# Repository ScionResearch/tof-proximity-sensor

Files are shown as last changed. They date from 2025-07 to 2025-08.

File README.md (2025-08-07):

# ESP32-C6 Configurable Proximity Sensor

**Version 1.0.1** - A configurable proximity sensor system built with ESP32-C6, featuring real-time web-based monitoring, advanced adaptive filtering, and secure OTA firmware updates.



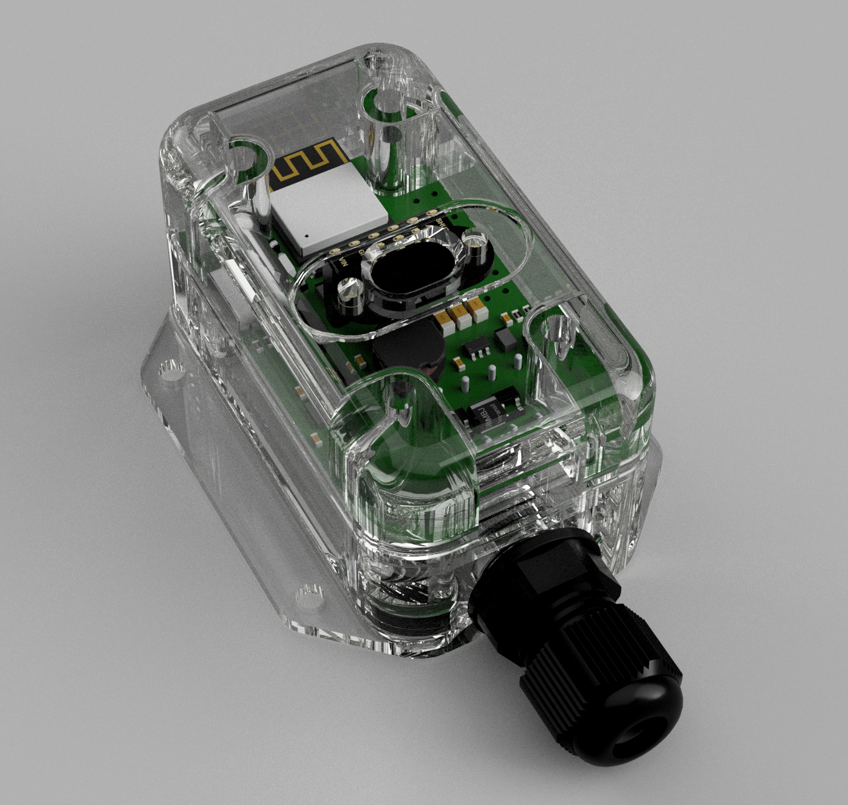
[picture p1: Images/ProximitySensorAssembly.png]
Proximity Sensor Assembly


## Features

### **🎯 Core Functionality**

- **VL53L1X ToF Sensor** - Accurate distance measurement up to 4 meters
- **Advanced Adaptive Filtering** - Intelligent noise reduction with rapid adaptation to sustained changes
- **Variance-Based Noise Detection** - Automatic detection and filtering of noisy environments
- **Dual Configurable Outputs** - Independent range, hysteresis, and polarity control
- **Smart Fault Detection** - Distinguishes genuine sensor faults from normal out-of-range conditions
- **Automatic Recovery** - Self-healing sensor initialization with enhanced reliability
- **Rapid Response Fix** - Outputs properly reset when objects are quickly removed

### **🌐 Web Interface**

- **Real-time Monitoring** - 5Hz update rate for smooth feedback
- **Live Configuration** - Adjust ranges, hysteresis, and polarity without reprogramming
- **Individual Output Control** - Enable/disable each output independently
- **Password Authentication** - Secure access with configurable admin password
- **Dynamic Visual Feedback** - Color-coded status and output indicators
- **Mobile-Optimized Design** - Clean, touch-friendly interface for smartphones
- **iOS Compatibility** - Enhanced captive portal support for reliable iPhone/iPad access

### **🔄 Over-The-Air (OTA) Updates**

- **Secure Firmware Updates** - Upload new firmware directly through web interface
- **Multi-Layer Security** - File validation, size checks, and integrity verification
- **Visual Feedback** - Orange LED indication during firmware update process
- **Progress Monitoring** - Real-time upload progress with detailed status messages
- **Safe Recovery** - Automatic rollback on failed updates with device protection

### **🔧 Hardware Integration**

- **WS2812 RGB LED** - Enhanced visual status indication:
  - **Green**: Normal operation (pulsing effect)
  - **Blue**: Triggered state
  - **Red**: Sensor fault or error
  - **Orange**: Firmware update in progress
- **Two Digital Outputs** - Configurable trigger logic with hysteresis
- **Persistent Storage** - Configuration saved to LittleFS flash memory
- **Unique WiFi SSID** - MAC-based identifier for multi-sensor deployments (fixed in v1.0.0)
- **Enhanced Diagnostics** - Comprehensive serial logging for troubleshooting

## Hardware Requirements

### **Main Components**

- **ESP32-C6-Mini** development module
- **VL53L1X** Time-of-Flight distance sensor
- **WS2812** RGB LED (NeoPixel)
- **Custom PCB** with two digital output channels

## Quick Start Guide

### **1. First Boot**

1. Power on the device
2. Look for WiFi network: `ToF-Prox-XXXXXX` (where XXXXXX = last 3 bytes of MAC address)
3. Connect using password: `sensor123`

### **2. Web Interface Access**

1. Open browser and navigate to: `http://192.168.4.1`
2. Login with default credentials:
   - **Password:** `admin`

### **3. Initial Configuration**

1. **Change Admin Password** (recommended):

   - Scroll to "Change Password" section
   - Enter current password: `admin`
   - Set new password and confirm
   - Click "Change Password"
2. **Configure Outputs**:

   - Adjust ranges, hysteresis, and polarity as needed
   - Click "Save Configuration"

## Default Settings

### **Network Configuration**

- **WiFi SSID:** `ToF-Prox-XXXXXX` (unique per device)
- **WiFi Password:** `sensor123`
- **IP Address:** `192.168.4.1`
- **Web Interface:** `http://192.168.4.1`

### **Authentication**

- **Default Admin Password:** `admin`
- **Important:** Change the default password after first login!

## Changelog

### **Version 1.0.1** (Latest)

#### 🔧 **Bug Fixes**
- **Fixed Output Trigger Logic**: Outputs configured as "Active out of range" now properly trigger when sensor readings exceed maximum detection range
- **Improved Out-of-Range Handling**: Enhanced logic for handling sensor readings beyond physical detection limits

#### 📱 **Mobile Enhancements**
- **Smart Firmware Update Restriction**: Firmware update panel automatically hidden on smartphones to ensure updates are only performed from PCs
- **Mobile Device Detection**: JavaScript-based user agent detection prevents accidental firmware updates from mobile devices
- **Enhanced Mobile Layout**: Improved responsive design for better mobile user experience

#### 🎨 **UI/UX Improvements**
- **Professional Layout**: Implemented CSS Grid layout for perfect form field alignment across all sections
- **Consistent Status Cards**: Fixed status card height inconsistencies for better visual alignment
- **Responsive Design**: Enhanced mobile breakpoint handling with single-column layout on small screens
- **Visual Consistency**: Improved spacing, padding, and visual hierarchy throughout the interface

#### 🏢 **Branding**
- **Company Logo Integration**: Embedded BSI logo in header with professional dark background styling
- **Responsive Logo Sizing**: Logo scales appropriately across desktop and mobile devices
- **Enhanced Visual Identity**: Improved page aesthetics with proper logo placement and contrast

#### 🔧 **Technical Improvements**
- **Base64 Logo Embedding**: Optimized logo delivery with embedded encoding for faster loading
- **Improved CSS Architecture**: Better organized stylesheets with consistent naming conventions
- **Enhanced JavaScript**: More robust mobile detection and UI interaction handling

### **Version 1.0.0**
- Initial release with core proximity sensor functionality
- Web-based configuration interface
- OTA firmware update capability
- Advanced adaptive filtering
- Dual configurable outputs

### **Sensor Configuration**

- **Timing Budget:** 50ms
- **Adaptive Filtering:** Intelligent noise reduction with rapid adaptation
- **Variance Threshold:** Automatic noise detection and filtering
- **Update Rate:** 5Hz web interface refresh
- **Change Detection:** Sustained change detection for rapid adaptation

### **Output Defaults**

| Output | Enabled | Min Range | Max Range | Hysteresis | Polarity |
|---|---|---|---|---|---|
| Output 1 | Disabled | 0mm | 100mm | 25mm | Active In Range |
| Output 2 | Disabled | 0mm | 100mm | 25mm | Active In Range |

### **Factory Reset**

- Connect a jumper from GND to the Factory Reset pin (pin 17).
- Power cycle or reset the device, leave the jumper in place until the LED turns green.
- All settings will be reset to default, including web admin password.

## Web Interface Guide

### **Status Monitoring**

- **Distance Display:** Shows actual distance in mm or "Out of range"
- **Status Panel:** Color-coded system status
  - 🟢 Green: Normal operation
  - 🔵 Blue: Output triggered
  - 🔴 Red: Sensor fault
- **Output Status:** Real-time ON/OFF indication with color feedback

### **Configuration Options**

#### **Output Settings**

- **Enable/Disable:** Individual control for each output
  - Unchecked = Output disabled (always OFF)
  - Checked = Output follows detection logic
- **Min/Max Distance:** Set detection range (0-2000mm)
- **Hysteresis:** Prevent output chatter (0-500mm)
- **Polarity:** 
  - "Active In Range" = Output ON when object is between Min-Max
  - "Active Out of Range" = Output ON when object is outside Min-Max

#### **Security Settings**

- **Change Password:** Update admin password with confirmation
- **Logout:** Secure session termination

## LED Status Indicators

| Color | Status | Description |
| --- | --- | --- |
| 🟢**Green** | Normal | Sensor operating normally |
| 🔵**Blue** | Triggered | Object detected in configured range |
| 🔴**Red Blinking** | Fault | Sensor hardware fault detected |
| 🟡**Yellow** | Initializing | System startup in progress |

## Technical Specifications

### **Sensor Performance**

- **Range:** 0mm to 2000mm (typical)
- **Accuracy:** ±3% of distance
- **Update Rate:** Up to 20Hz (50ms timing budget)
- **Field of View:** 27° (full width)

### **System Specifications**

- **Supply Voltage:** +12V-24V DC 100mA max
- **Microcontroller:** ESP32-C6 (160MHz, 320KB RAM, 4MB Flash)
- **WiFi:** 802.11 b/g/n (2.4GHz)
- **Operating Temperature:** -10°C to +60°C

### **Output Specifications**

- **Digital Outputs:** 2 channels open drain
- **Max Voltage at Outputs:** +33V DC
- **Current Capacity:** 100mA per output source capacity
- **Response Time:** <100ms (including hysteresis)

## Development Environment

### **PlatformIO Configuration**

```ini
[env:esp32-c6-devkitm-1]
platform = https://github.com/pioarduino/platform-espressif32/releases/download/54.03.20/platform-espressif32.zip
board = esp32-c6-devkitm-1
framework = arduino
build_flags = 
    -D ARDUINO_USB_MODE=1
    -D ARDUINO_USB_CDC_ON_BOOT=1
    -D ESP32_C6_env
lib_deps = 
    adafruit/Adafruit NeoPixel@^1.15.1
    adafruit/Adafruit VL53L1X@^3.1.2
    bblanchon/ArduinoJson@^7.0.4
    ESP32Async/AsyncTCP
    ESP32Async/ESPAsyncWebServer
```

### **Required Libraries**

- **Adafruit NeoPixel** - WS2812 LED control
- **Adafruit VL53L1X** - ToF sensor interface
- **ArduinoJson** - Configuration serialization
- **ESP32Async/AsyncTCP** - Async networking (ESP32-C6 compatible)
- **ESP32Async/ESPAsyncWebServer** - Web server framework

## Troubleshooting

### **Common Issues**

#### **Cannot Connect to WiFi**

- Verify SSID format: `ToF-Prox-XXXXXX`
- Check password: `sensor123`
- Ensure device is powered and LED is active
- Try power cycling the device

#### **Web Interface Not Loading**

- Confirm connection to correct WiFi network
- Navigate to: `http://192.168.4.1` (not https)
- Clear browser cache if needed
- Try different browser

#### **Sensor Shows "Out of range"**

- Normal when no object is within detection range (0mm-2000mm)
- Check sensor alignment and cleanliness
- Verify object is within sensor field of view (27°)

#### **Outputs Not Triggering**
- **Check if outputs are enabled** - Both outputs are disabled by default for safety
- Verify configuration ranges are appropriate for your application
- Check hysteresis settings (too high may prevent triggering)
- Confirm polarity setting matches your requirements
- Test with known object at specific distance

#### **Red LED (Fault Condition)**

- Power cycle the device (automatic recovery attempts every 5 seconds)
- Check I2C connections to VL53L1X sensor
- Verify sensor is not obstructed or damaged

## Multi-Sensor Deployment

### **Network Planning**

- Each sensor creates unique SSID based on MAC address
- No network conflicts when multiple sensors are deployed
- Individual configuration and monitoring per sensor
- Suitable for industrial and commercial installations

### **Identification**

- SSID format: `ToF-Prox-XXXXXX`
- Serial monitor shows actual SSID during startup
- MAC address visible in device information

## Applications

### **Industrial Automation**

- Conveyor belt object detection
- Material level sensing
- Robotic positioning feedback
- Quality control measurements

### **Security Systems**

- Perimeter detection
- Access control triggers
- Intrusion detection
- Vehicle presence sensing

### **Smart Building**

- Occupancy detection
- Automatic door control
- Parking space monitoring
- Energy management triggers

## Changelog

### **Version 1.0.0** - *August 2025*

#### 🚀 **Major Features**

- **Over-The-Air (OTA) Firmware Updates**
  - Secure web-based firmware upload interface
  - Multi-layer security validation (file type, size, integrity)
  - Visual feedback with orange LED during updates
  - Real-time progress monitoring
  - Automatic rollback on failed updates

- **Advanced Adaptive Filtering System**
  - Replaced simple moving average with intelligent adaptive filter
  - Variance-based noise detection and filtering
  - Rapid adaptation to sustained changes while filtering noise
  - Configurable thresholds for different environments
  - Enhanced signal quality assessment

#### 🔧 **Improvements**

- **Fixed SSID Uniqueness Issue**
  - Resolved static MAC address problem in WiFi AP mode
  - Each device now generates truly unique SSID based on hardware MAC
  - Proper WiFi initialization sequence ensures correct MAC retrieval

- **Enhanced Output Trigger Logic**
  - Fixed output lock-up when objects are quickly removed
  - Outputs now properly reset when sensor goes out of range
  - Improved hysteresis handling for rapid distance changes
  - Added comprehensive debug logging for troubleshooting

- **LED Status Enhancements**
  - Added orange LED indication during firmware updates
  - Enhanced pulsing effects for normal operation
  - Improved visual feedback for all system states

#### 🛡️ **Security & Reliability**

- **Firmware Validation**
  - File extension validation (only .bin files accepted)
  - Size validation (minimum/maximum limits)
  - Free space verification before update
  - ESP32 built-in checksum verification

- **Enhanced Error Handling**
  - Improved sensor fault detection and recovery
  - Better distinction between genuine faults and out-of-range conditions
  - Automatic sensor reinitialization on communication errors

#### 📱 **Web Interface Updates**

- **OTA Update Section**
  - Dedicated firmware update interface
  - Current version and build date display
  - Security warnings and user guidance
  - Progress indicators and status messages

- **Enhanced Diagnostics**
  - Real-time variance and noise level display
  - Adaptive filter status indicators
  - Comprehensive system information

#### 🔧 **Technical Improvements**

- **Code Organization**
  - Modular filter classes (NoiseFilter, AdaptiveFilter)
  - Improved separation of concerns
  - Enhanced maintainability and extensibility

- **Performance Optimizations**
  - Reduced memory usage in filtering algorithms
  - Optimized sensor reading processing
  - Improved web interface responsiveness

#### 📋 **Configuration**

- **Version Information**
  - Added FW_VERSION constant (1.0.0)
  - Version display in web interface
  - Build date tracking

---

## License

This project is open source. Please refer to the LICENSE file for details.

## Contributing

Contributions are welcome! Please feel free to submit pull requests or open issues for bugs and feature requests.

## Support

For technical support or questions:

1. Check this README for common solutions
2. Review the troubleshooting section
3. Open an issue on GitHub with detailed description
4. Include serial monitor output when reporting bugs

---

**⚠️ Security Note:** Always change the default admin password (`admin`) after first login to secure your device!

**📝 Note:** This sensor is designed for indoor use. For outdoor applications, ensure appropriate weatherproofing of the electronics.

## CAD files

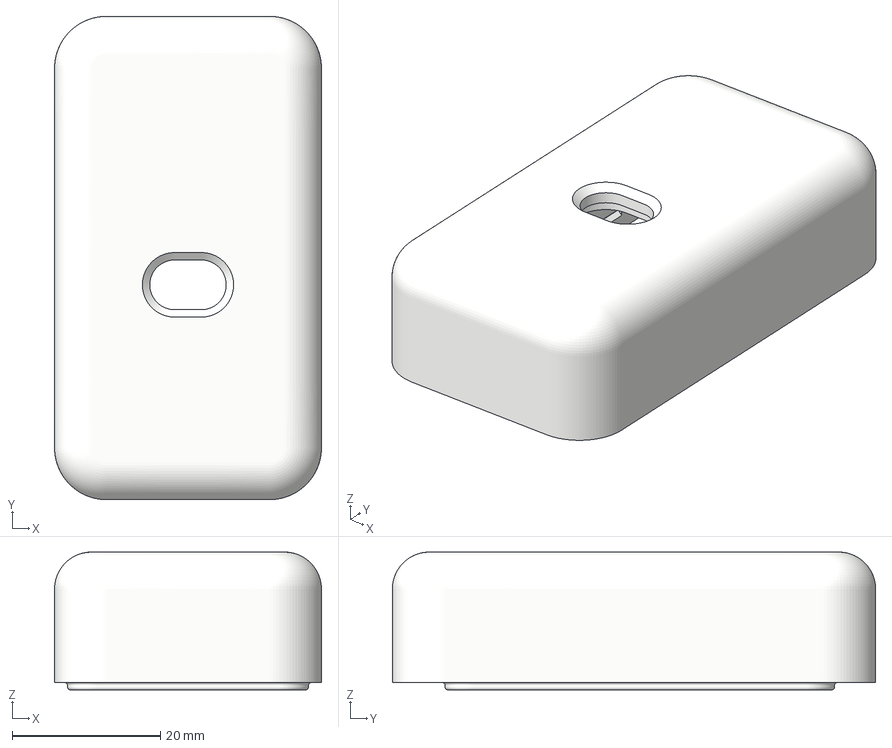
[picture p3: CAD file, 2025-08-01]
CAD/Enclosure/Top.3mf
36.0 x 65.2 x 18.6 mm

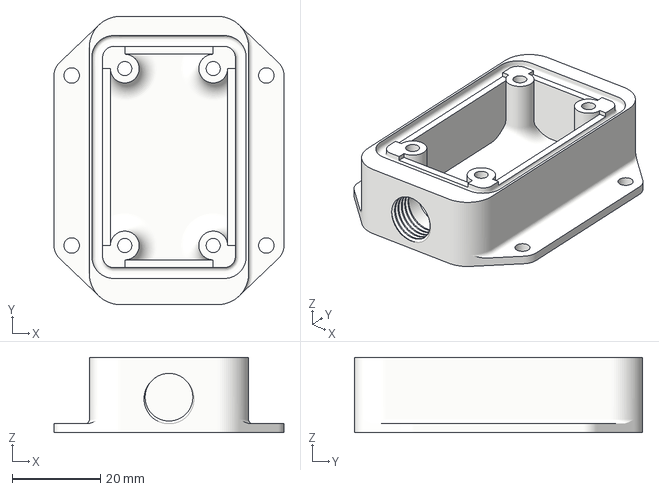
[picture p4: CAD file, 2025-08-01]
CAD/Enclosure/Base.3mf
52.0 x 65.2 x 17.0 mm

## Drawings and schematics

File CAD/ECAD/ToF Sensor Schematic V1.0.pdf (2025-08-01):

## Control power supplies

## USB interface

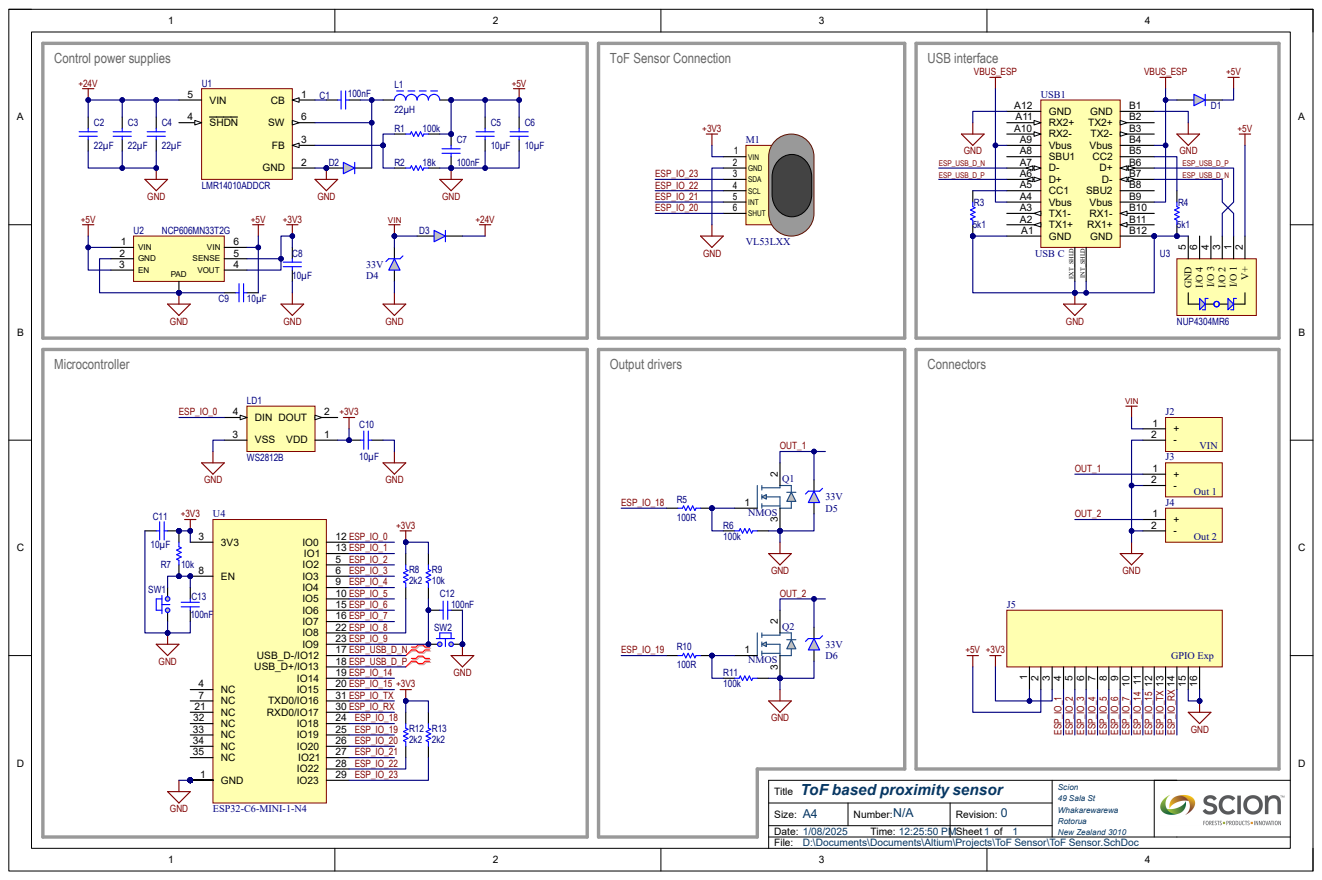
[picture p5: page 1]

ToF based proximity sensor
Title
D:\Documents\Documents\Altium\Projects\ToF Sensor\ToF Sensor.SchDoc

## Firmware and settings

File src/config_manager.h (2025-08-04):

#pragma once

#include <Arduino.h>
#include <WiFi.h>
#include <ArduinoJson.h>
#include <LittleFS.h>
#include "sys_init.h"

// Default configuration values
#define DEFAULT_AP_SSID "ProximitySensor"
#define DEFAULT_AP_PASSWORD "sensor123"
#define DEFAULT_ADMIN_PASSWORD "admin"
#define CONFIG_FILE_PATH "/config.json"
#define HISTORY_FILE_PATH "/history.json"

// WiFi and web server settings
#define AP_CHANNEL 1
#define AP_MAX_CONNECTIONS 4
#define WEB_SERVER_PORT 80

// History settings
#define MAX_HISTORY_POINTS 60  // 1 minute at 1Hz
#define HISTORY_INTERVAL_MS 1000

struct WiFiConfig {
    String ap_ssid;
    String ap_password;
    String admin_password;
    bool ap_enabled;
};

struct DeviceConfig {
    String device_name;
    uint16_t output1_min;
    uint16_t output1_max;
    uint16_t output1_hysteresis;
    bool output1_active_in_range;
    bool output1_enabled;
    
    uint16_t output2_min;
    uint16_t output2_max;
    uint16_t output2_hysteresis;
    bool output2_active_in_range;
    bool output2_enabled;
};

struct HistoryPoint {
    uint32_t timestamp;
    int16_t distance;
    bool output1_state;
    bool output2_state;
};

class ConfigManager {
private:
    WiFiConfig wifi_config;
    DeviceConfig device_config;
    HistoryPoint history_buffer[MAX_HISTORY_POINTS];
    uint8_t history_index;
    uint8_t history_count;
    uint32_t last_history_time;
    
    bool loadConfigFromFile();
    bool saveConfigToFile();
    void setDefaultConfig();

public:
    ConfigManager();
    
    bool initialize();
    void addHistoryPoint(int16_t distance, bool out1_state, bool out2_state);
    
    // WiFi configuration
    WiFiConfig getWiFiConfig() { return wifi_config; }
    void setWiFiConfig(const WiFiConfig& config);
    
    // Device configuration  
    DeviceConfig getDeviceConfig() { return device_config; }
    void setDeviceConfig(const DeviceConfig& config);
    
    // Authentication
    bool validatePassword(const String& password);
    void setAdminPassword(const String& password);
    
    // History management
    String getHistoryJson();
    void clearHistory();
    
    // File operations
    bool saveConfig();
    bool resetToDefaults();
    
    // JSON serialization
    String getConfigJson();
    bool setConfigFromJson(const String& json);
};

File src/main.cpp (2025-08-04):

#include "sys_init.h"
#include "sensor_manager.h"
#include "config_manager.h"
#include "web_server.h"

// Global instances
SensorManager* sensorManager;
ConfigManager* configManager;
WebServerManager* webServer;
Adafruit_NeoPixel led = Adafruit_NeoPixel(1, PIN_LED_DATA, NEO_GRB + NEO_KHZ800);
Adafruit_VL53L1X vl53 = Adafruit_VL53L1X(PIN_TOF_SHUTDOWN, PIN_TOF_INT);

void setup() {
    Serial.begin(115200);
    while (!Serial) delay(10);
    
    Serial.println("=== ESP32-C6 Configurable Proximity Sensor ===");
    Serial.println("Initializing system...");
    
    // Initialize LED
    led.begin();
    led.setPixelColor(0, led.Color(255, 255, 0)); // Yellow during init
    led.show();
    
    // Initialize configuration manager
    Serial.println("Initializing configuration manager...");
    configManager = new ConfigManager();
    if (!configManager->initialize()) {
        Serial.println("Configuration manager initialization FAILED!");
        led.setPixelColor(0, led.Color(255, 0, 0)); // Red for error
        led.show();
        while(1) delay(1000); // Halt on critical error
    }
    
    // Create sensor manager instance
    Serial.println("Initializing sensor manager...");
    sensorManager = new SensorManager(&vl53, &led, PIN_OUT_1, PIN_OUT_2);
    
    // Initialize sensor
    if (sensorManager->initialize()) {
        Serial.println("Sensor initialization complete!");
        
        // Load configuration from storage and apply to sensor manager
        DeviceConfig device_config = configManager->getDeviceConfig();
        
        sensorManager->setOutput1Config(
            device_config.output1_min,
            device_config.output1_max,
            device_config.output1_hysteresis,
            device_config.output1_active_in_range
        );
        
        sensorManager->setOutput2Config(
            device_config.output2_min,
            device_config.output2_max,
            device_config.output2_hysteresis,
            device_config.output2_active_in_range
        );
        
        sensorManager->enableOutput1(device_config.output1_enabled);
        sensorManager->enableOutput2(device_config.output2_enabled);
        
        Serial.println("Configuration loaded and applied to sensor manager");
        Serial.print("Output 1: ");
        Serial.print(device_config.output1_enabled ? "ENABLED" : "DISABLED");
        Serial.print(" - Range: ");
        Serial.print(device_config.output1_min);
        Serial.print("-");
        Serial.print(device_config.output1_max);
        Serial.print("mm (hysteresis: ");
        Serial.print(device_config.output1_hysteresis);
        Serial.print("mm, active ");
        Serial.println(device_config.output1_active_in_range ? "in range" : "out of range");
        
        Serial.print("Output 2: ");
        Serial.print(device_config.output2_enabled ? "ENABLED" : "DISABLED");
        Serial.print(" - Range: ");
        Serial.print(device_config.output2_min);
        Serial.print("-");
        Serial.print(device_config.output2_max);
        Serial.print("mm (hysteresis: ");
        Serial.print(device_config.output2_hysteresis);
        Serial.print("mm, active ");
        Serial.println(device_config.output2_active_in_range ? "in range" : "out of range");
        
    } else {
        Serial.println("Sensor initialization FAILED!");
    }
    
    // Initialize web server
    Serial.println("Initializing web server...");
    webServer = new WebServerManager(configManager, sensorManager);
    if (webServer->startAccessPoint()) {
        if (webServer->initialize()) {
            Serial.println("Web server started successfully");
        } else {
            Serial.println("Web server initialization failed");
        }
    } else {
        Serial.println("Failed to start Access Point");
    }
    
    Serial.println("Core functionality:");
    Serial.println("- Distance measurement with moving average");
    Serial.println("- LED status feedback");
    Serial.println("- Configurable output control");
    Serial.println("- Persistent configuration storage");
    Serial.println("================================");
    Serial.println("PROXIMITY SENSOR READY");
    Serial.println("Core functionality:");
    Serial.println("- Distance measurement with moving average");
    Serial.println("- LED status feedback");
    Serial.println("- Configurable output control");
    Serial.println("- Persistent configuration storage");
    Serial.println("================================");
    Serial.println("Note: Web interface will be enabled in future update");
    Serial.println("Monitor serial output for real-time status");
    Serial.println("================================");
    
    Serial.println("System initialization complete! Starting main loop...");
}

void loop() {
    // Update sensor manager (handles all sensor reading, filtering, and output control)
    sensorManager->update();
    
    // Handle web server requests
    webServer->handleClient();
    
    // Add data to history buffer for web interface
    if (sensorManager->isSensorReady()) {
        configManager->addHistoryPoint(
            sensorManager->getDistance(),
            sensorManager->getOutput1Config().current_state,
            sensorManager->getOutput2Config().current_state
        );
    }
    
    // Print status every 5 seconds (reduced frequency for cleaner output)
    static uint32_t last_status_print = 0;
    if (millis() - last_status_print > 5000) {
        last_status_print = millis();
        
        if (sensorManager->isSensorReady()) {
            Serial.print("[STATUS] Distance: ");
            Serial.print(sensorManager->getDistance());
            Serial.print("mm (raw: ");
            Serial.print(sensorManager->getRawDistance());
            Serial.print("mm) | Status: ");
            
            switch (sensorManager->getStatus()) {
                case STATUS_OK:
                    Serial.print("OK");
                    break;
                case STATUS_TRIGGERED:
                    Serial.print("TRIGGERED");
                    break;
                case STATUS_FAULT:
                    Serial.print("FAULT");
                    break;
            }
            
            Serial.print(" | Out1: ");
            Serial.print(sensorManager->getOutput1Config().current_state ? "ON" : "OFF");
            Serial.print(" | Out2: ");
            Serial.print(sensorManager->getOutput2Config().current_state ? "ON" : "OFF");
            Serial.print(" | WiFi Clients: ");
            Serial.println(WiFi.softAPgetStationNum());
        } else {
            Serial.println("[STATUS] Sensor not ready or in fault state");
        }
    }
    
    // Small delay to prevent overwhelming the system
    delay(50);
}

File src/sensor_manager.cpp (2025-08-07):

#include "sensor_manager.h"

// MovingAverage implementation
MovingAverage::MovingAverage(uint8_t buffer_size) {
    size = buffer_size;
    buffer = new int16_t[size];
    reset();
}

MovingAverage::~MovingAverage() {
    delete[] buffer;
}

void MovingAverage::addValue(int16_t value) {
    // Remove old value from sum if buffer is full
    if (count == size) {
        sum -= buffer[index];
    } else {
        count++;
    }
    
    // Add new value
    buffer[index] = value;
    sum += value;
    
    // Move to next position
    index = (index + 1) % size;
}

int16_t MovingAverage::getAverage() {
    if (count == 0) return 0;
    return sum / count;
}

void MovingAverage::reset() {
    index = 0;
    count = 0;
    sum = 0;
    for (uint8_t i = 0; i < size; i++) {
        buffer[i] = 0;
    }
}

bool MovingAverage::isReady() {
    return count >= (size / 2); // Ready when at least half full
}

float MovingAverage::getVariance() {
    if (count < 2) return 0.0;
    
    float mean = (float)sum / count;
    float variance_sum = 0.0;
    
    for (uint8_t i = 0; i < count; i++) {
        float diff = buffer[i] - mean;
        variance_sum += diff * diff;
    }
    
    return variance_sum / (count - 1);
}

int16_t MovingAverage::getMedian() {
    if (count == 0) return 0;
    
    // Create a copy of the buffer for sorting
    int16_t* sorted = new int16_t[count];
    for (uint8_t i = 0; i < count; i++) {
        sorted[i] = buffer[i];
    }
    
    // Simple insertion sort
    for (uint8_t i = 1; i < count; i++) {
        int16_t key = sorted[i];
        int j = i - 1;
        while (j >= 0 && sorted[j] > key) {
            sorted[j + 1] = sorted[j];
            j--;
        }
        sorted[j + 1] = key;
    }
    
    int16_t median = sorted[count / 2];
    delete[] sorted;
    return median;
}

// NoiseFilter implementation
NoiseFilter::NoiseFilter(uint8_t buffer_size) {
    size = buffer_size;
    buffer = new int16_t[size];
    reset();
}

NoiseFilter::~NoiseFilter() {
    delete[] buffer;
}

void NoiseFilter::insertionSort(int16_t* arr, uint8_t n) {
    for (uint8_t i = 1; i < n; i++) {
        int16_t key = arr[i];
        int j = i - 1;
        while (j >= 0 && arr[j] > key) {
            arr[j + 1] = arr[j];
            j--;
        }
        arr[j + 1] = key;
    }
}

bool NoiseFilter::isOutlier(int16_t value, int16_t median, uint16_t threshold) {
    return abs(value - median) > threshold;
}

bool NoiseFilter::addValue(int16_t value) {
    // If we have enough samples, check if this is an outlier
    if (count >= 3) {
        int16_t current_median = getMedian();
        if (isOutlier(value, current_median, MAX_OUTLIER_DEVIATION)) {
            Serial.print("Rejecting outlier: ");
            Serial.print(value);
            Serial.print(" (median: ");
            Serial.print(current_median);
            Serial.println(")");
            return false; // Reject outlier
        }
    }
    
    // Remove old value from sum if buffer is full
    if (count == size) {
        sum -= buffer[index];
    } else {
        count++;
    }
    
    // Add new value
    buffer[index] = value;
    sum += value;
    
    // Move to next position
    index = (index + 1) % size;
    return true; // Value accepted
}

int16_t NoiseFilter::getFilteredValue() {
    if (count == 0) return 0;
    
    // Use median for better outlier rejection
    return getMedian();
}

float NoiseFilter::getVariance() {
    if (count < 2) return 0.0;
    
    float mean = (float)sum / count;
    float variance_sum = 0.0;
    
    for (uint8_t i = 0; i < count; i++) {
        float diff = buffer[i] - mean;
        variance_sum += diff * diff;
    }
    
    return variance_sum / (count - 1);
}

int16_t NoiseFilter::getMedian() {
    if (count == 0) return 0;
    
    // Create a copy of the buffer for sorting
    int16_t* sorted = new int16_t[count];
    for (uint8_t i = 0; i < count; i++) {
        sorted[i] = buffer[i];
    }
    
    insertionSort(sorted, count);
    int16_t median = sorted[count / 2];
    delete[] sorted;
    return median;
}

void NoiseFilter::reset() {
    index = 0;
    count = 0;
    sum = 0;
    for (uint8_t i = 0; i < size; i++) {
        buffer[i] = 0;
    }
}

bool NoiseFilter::isReady() {
    return count >= (size / 2); // Ready when at least half full
}

uint8_t NoiseFilter::getValidSampleCount() {
    return count;
}

// AdaptiveFilter implementation
AdaptiveFilter::AdaptiveFilter(uint8_t buffer_size) {
    this->buffer_size = buffer_size;
    recent_readings = new int16_t[buffer_size];
    filtered_value = 0.0;
    recent_index = 0;
    recent_count = 0;
    change_confirmation_count = 0;
    change_detected = false;
    is_initialized = false;
    
    for (uint8_t i = 0; i < buffer_size; i++) {
        recent_readings[i] = 0;
    }
}

AdaptiveFilter::~AdaptiveFilter() {
    delete[] recent_readings;
}

bool AdaptiveFilter::detectSustainedChange(int16_t new_value) {
    if (!is_initialized) return false;
    
    float diff = abs(new_value - filtered_value);
    
    // Check if this reading represents a significant change
    if (diff > CHANGE_DETECTION_THRESHOLD) {
        change_confirmation_count++;
        Serial.print("Change detected: ");
        Serial.print(new_value);
        Serial.print(" vs filtered: ");
        Serial.print((int16_t)filtered_value);
        Serial.print(", diff: ");
        Serial.print((int16_t)diff);
        Serial.print(", count: ");
        Serial.println(change_confirmation_count);
        
        // Require multiple consecutive readings to confirm change
        if (change_confirmation_count >= CHANGE_CONFIRMATION_COUNT) {
            Serial.println("Sustained change confirmed - entering rapid adaptation mode");
            return true;
        }
    } else {
        // Reset change counter if reading is close to current filtered value
        if (change_confirmation_count > 0) {
            Serial.println("Change sequence broken - returning to normal filtering");
        }
        change_confirmation_count = 0;
    }
    
    return false;
}

float AdaptiveFilter::getAdaptationRate() {
    // Use aggressive adaptation when sustained change is detected
    return change_detected ? RAPID_ADAPT_ALPHA : NORMAL_ADAPT_ALPHA;
}
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

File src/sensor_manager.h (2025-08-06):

#pragma once

#include <Arduino.h>
#include <Adafruit_VL53L1X.h>
#include <Adafruit_NeoPixel.h>
#include "config_manager.h"

// Configuration constants
#define MOVING_AVERAGE_SIZE 5
#define MEDIAN_FILTER_SIZE 5
#define SENSOR_TIMEOUT_MS 1000
#define HYSTERESIS_DEFAULT 50  // mm
#define MAX_VARIANCE_THRESHOLD 10000  // mm^2 - readings with higher variance are rejected
#define MIN_SIGNAL_RATE_THRESHOLD 0.1  // Minimum signal rate for valid reading
#define MAX_OUTLIER_DEVIATION 100  // mm - reject readings this far from median
#define CHANGE_DETECTION_THRESHOLD 50  // mm - significant change threshold
#define CHANGE_CONFIRMATION_COUNT 3  // consecutive readings needed to confirm change
#define RAPID_ADAPT_ALPHA 0.7  // aggressive smoothing factor for confirmed changes
#define NORMAL_ADAPT_ALPHA 0.2  // conservative smoothing factor for normal operation

// LED status colors (RGB values)
#define LED_OK_R            0
#define LED_OK_G            255
#define LED_OK_B            0
#define LED_TRIGGERED_R     0
#define LED_TRIGGERED_G     0
#define LED_TRIGGERED_B     255
#define LED_FAULT_R         255
#define LED_FAULT_G         0
#define LED_FAULT_B         0
#define LED_OFF_R           0
#define LED_OFF_G           0
#define LED_OFF_B           0
#define LED_FW_UPDATE_R     255
#define LED_FW_UPDATE_G     150
#define LED_FW_UPDATE_B     0

// Device status enumeration
enum DeviceStatus {
    STATUS_OK,
    STATUS_TRIGGERED,
    STATUS_FAULT
};

// Output configuration structure
struct OutputConfig {
    bool enabled;
    uint16_t range_min;     // mm
    uint16_t range_max;     // mm
    uint16_t hysteresis;    // mm
    bool active_in_range;   // true = active when in range, false = active when out of range
    bool current_state;     // current output state
};

// Moving average filter class
class MovingAverage {
private:
    int16_t* buffer;
    uint8_t size;
    uint8_t index;
    uint8_t count;
    int32_t sum;

public:
    MovingAverage(uint8_t buffer_size);
    ~MovingAverage();
    void addValue(int16_t value);
    int16_t getAverage();
    void reset();
    bool isReady();
    float getVariance();  // Calculate variance of current samples
    int16_t getMedian();  // Get median value
};

// Enhanced noise filter with multiple strategies
class NoiseFilter {
private:
    int16_t* buffer;
    uint8_t size;
    uint8_t index;
    uint8_t count;
    int32_t sum;
    
    // Sorting helper for median calculation
    void insertionSort(int16_t* arr, uint8_t n);
    bool isOutlier(int16_t value, int16_t median, uint16_t threshold);
    
public:
    NoiseFilter(uint8_t buffer_size);
    ~NoiseFilter();
    
    bool addValue(int16_t value);  // Returns true if value was accepted
    int16_t getFilteredValue();
    float getVariance();
    int16_t getMedian();
    void reset();
    bool isReady();
    uint8_t getValidSampleCount();
};

// Adaptive filter that responds quickly to sustained changes but filters noise
class AdaptiveFilter {
private:
    float filtered_value;
    int16_t* recent_readings;
    uint8_t recent_index;
    uint8_t recent_count;
    uint8_t buffer_size;
    
    uint8_t change_confirmation_count;
    bool change_detected;
    bool is_initialized;
    
    bool detectSustainedChange(int16_t new_value);
    float getAdaptationRate();
    
public:
    AdaptiveFilter(uint8_t buffer_size = 5);
    ~AdaptiveFilter();
    
    void addValue(int16_t value);
    int16_t getFilteredValue();
    bool isChangeDetected() { return change_detected; }
    void reset();
    bool isReady() { return is_initialized; }
    float getVariance();
    uint8_t getValidSampleCount() { return recent_count; }
};

// Sensor manager class
class SensorManager {
private:
    Adafruit_VL53L1X* tof_sensor;
    Adafruit_NeoPixel* status_led;
    AdaptiveFilter* distance_filter;
    
    uint32_t last_reading_time;
    int16_t current_distance;
    int16_t filtered_distance;
    DeviceStatus device_status;
    
    OutputConfig output1_config;
    OutputConfig output2_config;
    
    uint8_t output1_pin;
    uint8_t output2_pin;
    
    bool sensor_initialized;
    uint8_t fault_count;
    bool out_of_range;
    
    // Enhanced noise detection
    uint16_t rejected_readings_count;
    float current_variance;
    float signal_rate;
    bool high_noise_detected;
    
    // OTA update mode tracking
    bool ota_update_mode;
    uint8_t custom_led_r, custom_led_g, custom_led_b;
    
    void updateLED();
    void updateOutputs();
    bool checkOutputTrigger(const OutputConfig& config, int16_t distance);

public:
    SensorManager(Adafruit_VL53L1X* tof, Adafruit_NeoPixel* led, uint8_t out1_pin, uint8_t out2_pin);
    ~SensorManager();
    
    bool initialize();
    void update();
    
    // Getters
    int16_t getDistance() { return filtered_distance; }
    int16_t getRawDistance() { return current_distance; }
    DeviceStatus getStatus() { return device_status; }
    bool isSensorReady() { return sensor_initialized && distance_filter->isReady(); }
    bool isOutOfRange() { return out_of_range; }
    
    // Enhanced noise detection getters
    float getVariance() { return current_variance; }
    float getSignalRate() { return signal_rate; }
    uint16_t getRejectedReadingsCount() { return rejected_readings_count; }
    bool isHighNoiseDetected() { return high_noise_detected; }
    uint8_t getValidSampleCount() { return distance_filter->getValidSampleCount(); }
    
    // Configuration methods
    void setOutput1Config(uint16_t min_range, uint16_t max_range, uint16_t hysteresis, bool active_in_range);
    void setOutput2Config(uint16_t min_range, uint16_t max_range, uint16_t hysteresis, bool active_in_range);
    void enableOutput1(bool enabled);
    void enableOutput2(bool enabled);
    void updateConfiguration(const DeviceConfig& config);
    
    // LED control methods for OTA updates
    void setOTAUpdateMode(bool enabled);
    void setCustomLEDColor(uint8_t r, uint8_t g, uint8_t b);
    
    OutputConfig getOutput1Config() { return output1_config; }
    OutputConfig getOutput2Config() { return output2_config; }
    
    // Reset and diagnostics
    void resetSensor();
    void factoryReset();
};

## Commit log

2025-07-31 Case correction
2025-08-01 Added CAD docs, added enable setting for outputs, chnaged webserver to captive for easier smart phone connection
    [Base.3mf, ToF Sensor.PrjPcb, ToF Sensor.SchDoc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]
2025-08-04 Implemented factory reset process
    [config_manager.cpp, config_manager.h, main.cpp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]
2025-08-06 Added OTA FW upload, better filtering. First major version 1.0.0
2025-08-07 Layout improvements, active out of range bug fix, version 1.0.1 release
    [sensor_manager.cpp, sys_init.h, web_server.cpp]
